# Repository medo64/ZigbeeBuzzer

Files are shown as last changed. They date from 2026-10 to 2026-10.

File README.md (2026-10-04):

# Zigbee Buzzer

Zigbee notification device allowing for multiple notifications using sound.

## Usage

When device is first used, button should be pressed to wake up the device. It
will immediately enter the pairing mode and remain in it for 3 minutes. If
device is not paired within 3 minutes, it will enter deep sleep again.

LED will be normally off. If LED is blinking slowly (about 1 Hz), device is
waiting to be paired. Fast double blinks will indicate communication error.

If device is paired, a short button press will cause device to immediately report
its state upon releasing.

Long press of 3-5s will make device enter pairing mode. LED will turn on once
3s interval starts and turn off after 5th second has passed.

Long press of 30-35 seconds will reset unit to factory settings and place it
into deep sleep until the next button press.

Long press while LED is off, will be ignored.

## Components

Each notification sound is exposed as a button.

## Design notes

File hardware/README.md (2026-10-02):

## Zigbee Buzzer Hardware

### Parts

|  # | Part | RefDes  |
|---:|---|---|
|  1 | C 10nF X7R 16V (0805) | C1 |
|  1 | C 10uF X5R 16V (0805) | C2 |
|  1 | D Schottky (SOD123F) | D1 |
|  1 | DS LED (0805) | DS1 |
|  1 | LS Passive Buzzer | LS1 |
|  1 | Q NPN 100mA 20V (SOT23-3) | Q1 |
|  1 | R 470 0.125W (0805) | R1 |
|  3 | R 1K 0.125W (0805) | R2-R4 |
|  1 | R 2.2K 0.125W (0805) | R5 |
|  2 | R 100K 0.125W (0805) | R6-R7 |
|  1 | S Tactile 4.0x4.0x1.5mm | S1 |
|  1 | U Wireless [Xiao ESP32-C6] | U1 |

#### Board Size

| | Dimensions | Area | Thickness |
|---|---|---|---|
| PCB |  26.0 x 21.0 mm | 0.9 in² | 0.8 mm |

#### Flyback diode

Diode is needed only if inductive diode is used (e.g. vibration motor). This is
used for testing purposes only at this time.

#### Battery

Battery can be optionally attached. This is currently used only for testing.

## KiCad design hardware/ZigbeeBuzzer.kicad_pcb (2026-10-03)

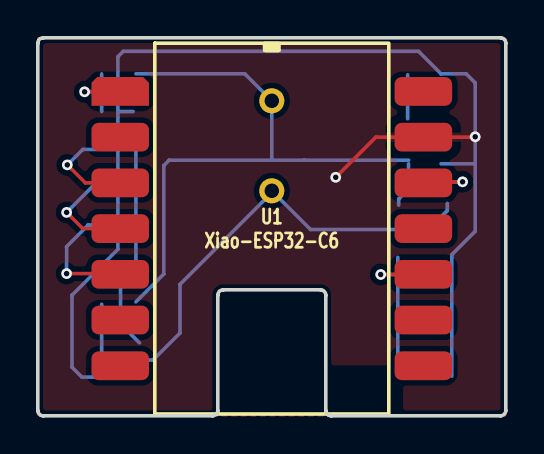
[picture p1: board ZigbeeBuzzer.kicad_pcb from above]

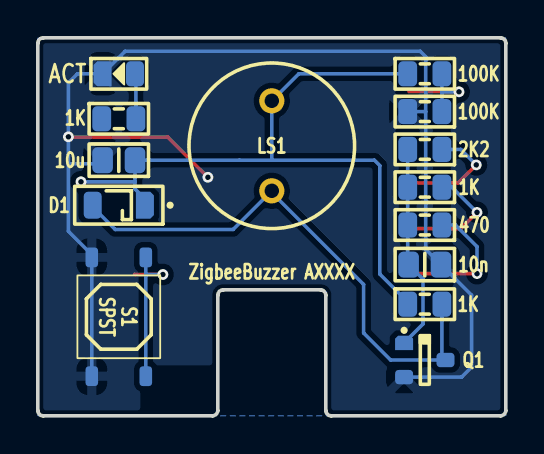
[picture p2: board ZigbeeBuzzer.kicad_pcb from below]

Board: 2 copper layers, 26.0 x 21.0 mm, 15 parts (14 on the bottom side), 10 nets.

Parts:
C1: 10n; C (0805)
C2: 10u; C (0805)
D1: CUS08F30; D Shottky (SOD123F)
DS1: ACT; DS (0805)
LS1: LS Buzzer (D9.5-H5.5)
Q1: NPN; Q Transistor NPN (SOT23-3)
R1: 470; R (0805)
R2, R3, R4: 1K; R (0805)
R5: 2K2; R (0805)
R7, R8: 100K; R (0805)
S1: SPST; S Tactile SPST-NO 12V 50mA 4.0x4.0x1.5mm (SMD-4)
U1: Xiao-ESP32-C6; U Wireless [Xiao ESP32C6] (SMD-14)

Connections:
3V3: C2.1, D1.1, LS1.1, R3.1, R7.1, U1.12
ADC: R7.2, R8.1, U1.1
BASE: C1.2, Q1.1, R1.2, R2.2, R5.2
BEEPER: D1.2, LS1.2, Q1.3, R3.2
BUTTON: S1.1, U1.10
GND: C1.1, C2.2, DS1.1, Q1.2, R8.2, S1.2, U1.13
LED: DS1.2, R4.2
PWM1: R5.1, U1.3
PWM2: R2.1, U1.4
PWM3: R1.1, U1.5

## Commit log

2026-09-30 Added 3V3 voltage divider
    [ZigbeeBuzzer.kicad_pcb]
2026-10-02 Added diode
    [ZigbeeBuzzer.kicad_pcb]
2026-10-03 Added PCB designator
    [ZigbeeBuzzer.kicad_pcb]
2026-10-11 Refactoring button location
2026-10-17 Updated buzzer footprint
2026-10-25 Added LED example
2026-10-31 Changed schottky diode footprint
2026-10-31 Initial switch setup
2026-11-01 Auto-reset for switches
2026-11-01 Better button handling
2026-11-02 Reworked code not to use timer interrupt
2026-11-02 Fixed ledcDetach not returning pin to high-impedance
2026-11-02 Updated volume resistor values
2026-11-03 Setting user LED
